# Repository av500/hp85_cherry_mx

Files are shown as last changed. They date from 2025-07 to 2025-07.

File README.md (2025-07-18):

 # HP 85 keyboard PCB using Cherry MX key switches

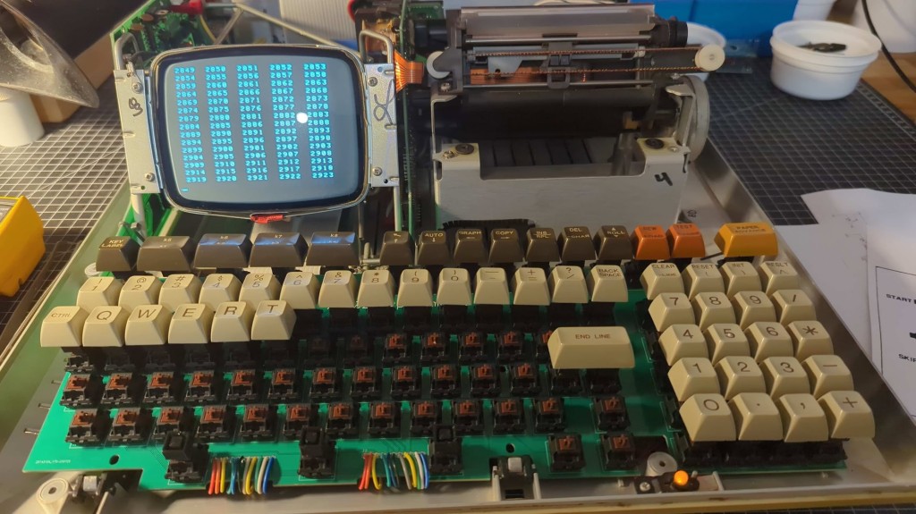
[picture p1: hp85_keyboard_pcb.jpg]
PCB image


(more images here: https://photos.app.goo.gl/D5baQ3GsZ5nenAsS6)

using the orignal keycaps with 3d-printerd adapters to connect the Hitek caps to the Cherry MX stem pattern:

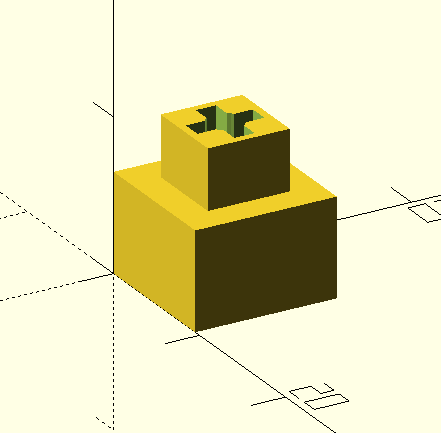
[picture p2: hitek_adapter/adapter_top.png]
adapter top view
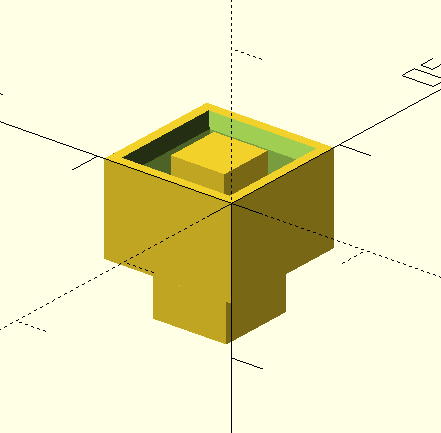
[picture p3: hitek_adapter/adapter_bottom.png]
adapter bottm view


the space bar uses three key switches in parallel with two 3d-printed standoffs in the corners:

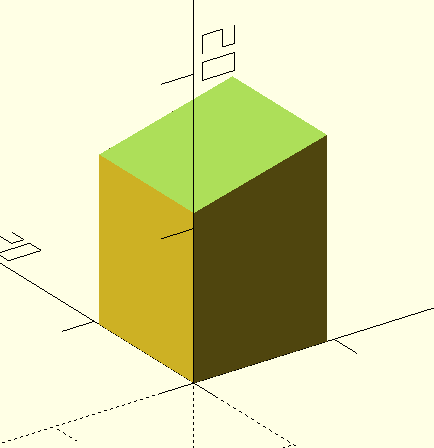
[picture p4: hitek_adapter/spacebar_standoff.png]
standoff 3d view
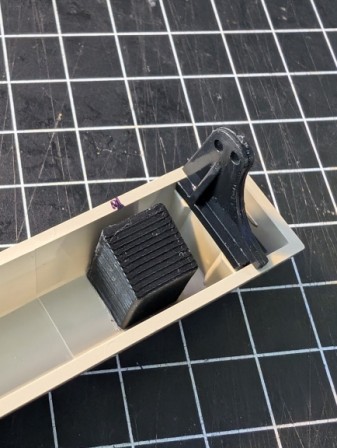
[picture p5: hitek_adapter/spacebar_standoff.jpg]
standoff view


**all 3d-printed part were designed to work with my (then) "not so good" printer, they might need some tweaking in terms of tolerances, I included the OpenSCAD source files.**

the PCB was made in standard 1.6mm thickness, so in order to make the keyboard stiffer a second PCB was placed below and the pin holes drilled out accordingly:

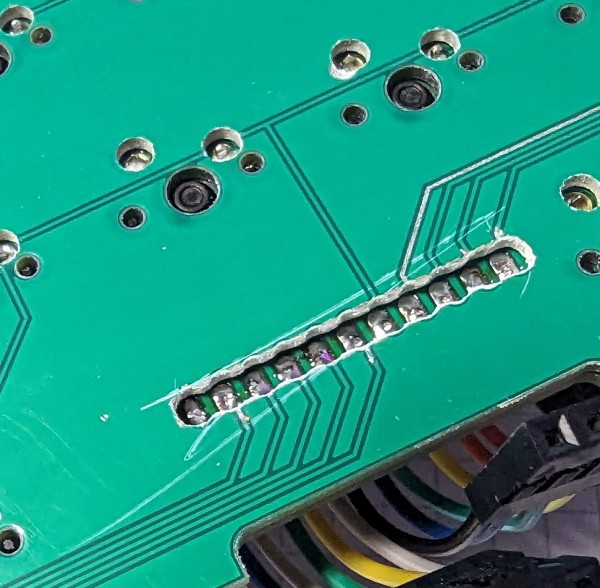
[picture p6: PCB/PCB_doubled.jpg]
doubled PCB


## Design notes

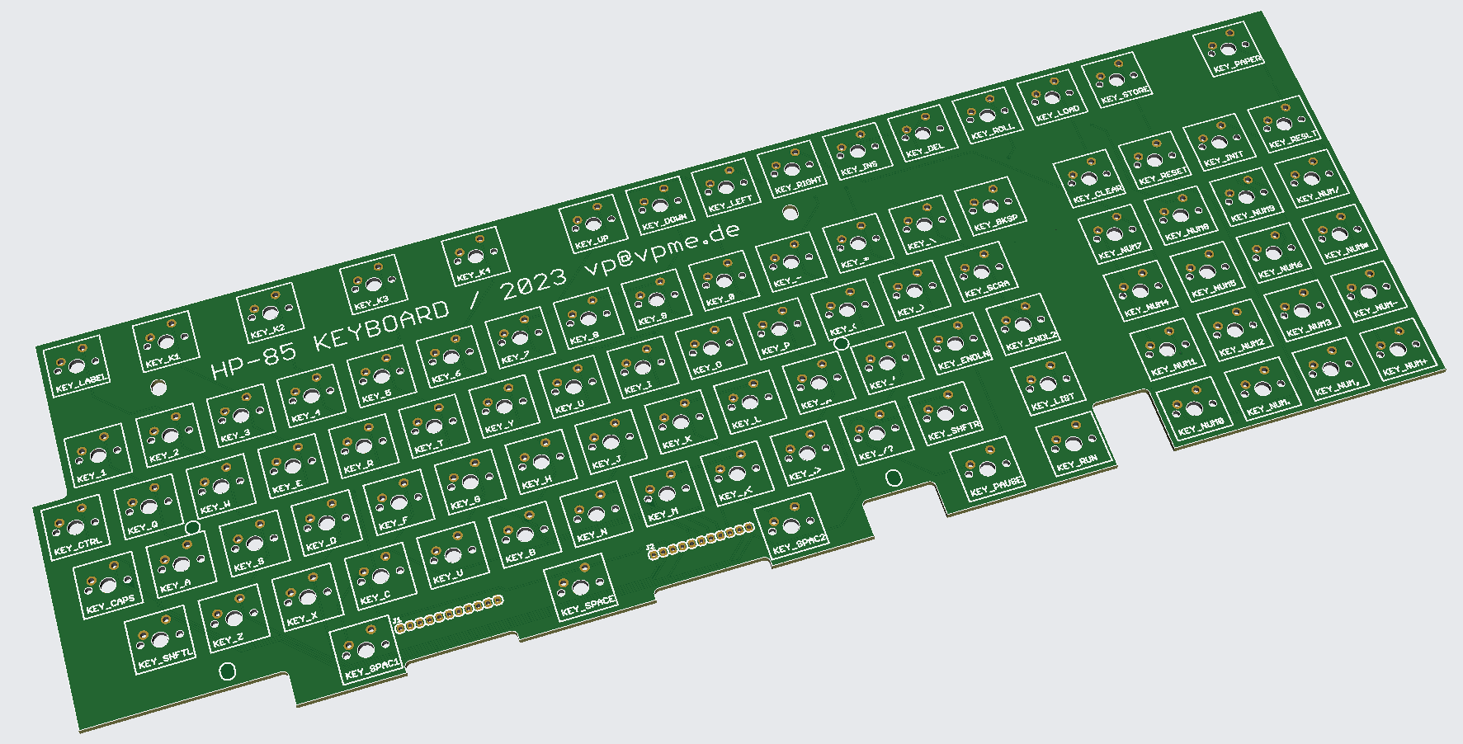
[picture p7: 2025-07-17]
PCB/HP85_keyboard_PCB_3d.png

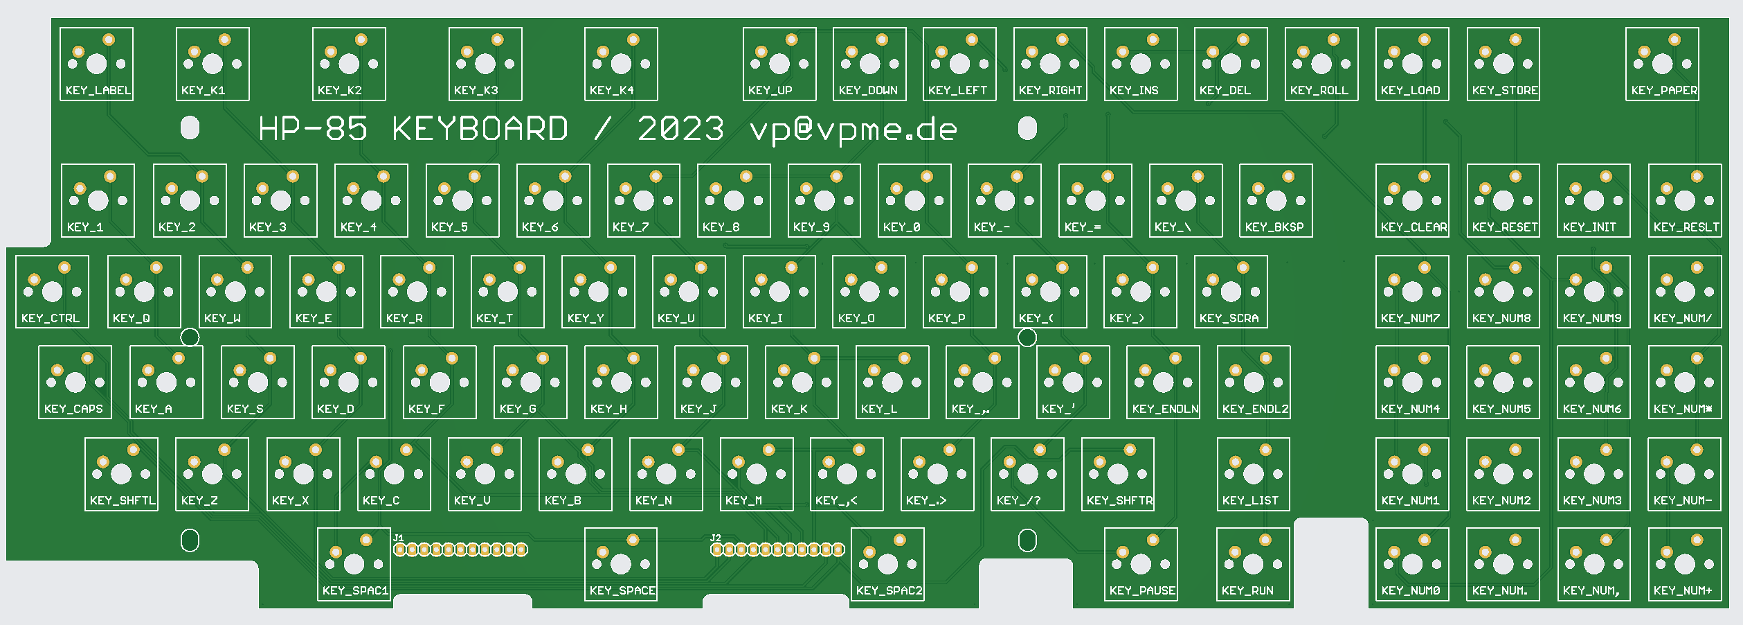
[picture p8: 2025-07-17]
PCB/HP85_keyboard_PCB_front.png

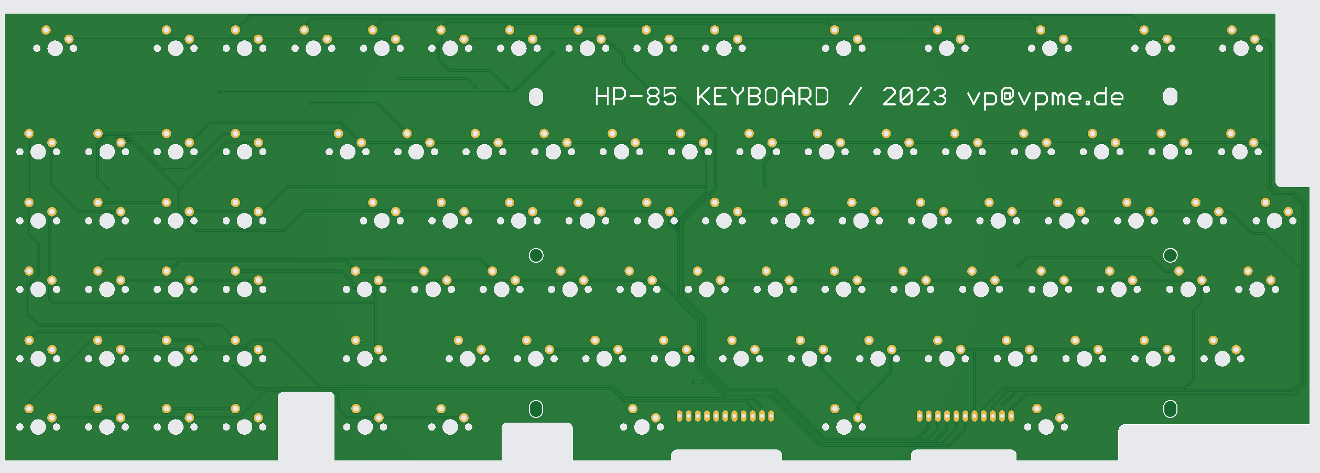
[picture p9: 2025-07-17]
PCB/HP85_keyboard_PCB_back.png

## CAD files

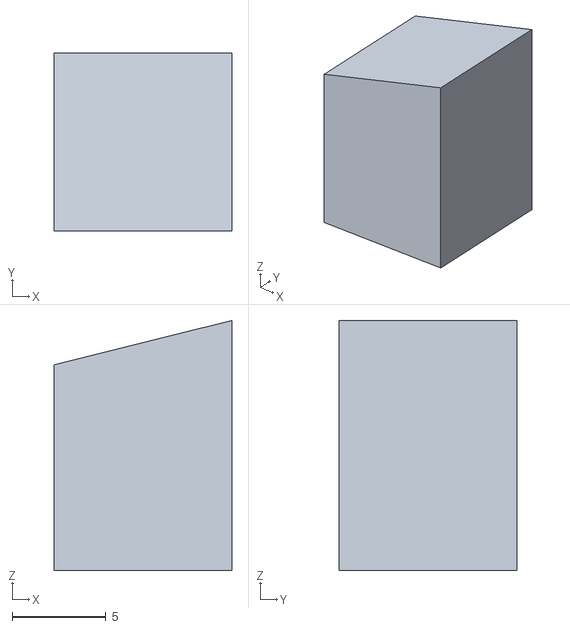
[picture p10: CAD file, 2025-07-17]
hitek_adapter/hitek_cherry_spacebar.stl
9.50 x 9.50 x 13.4

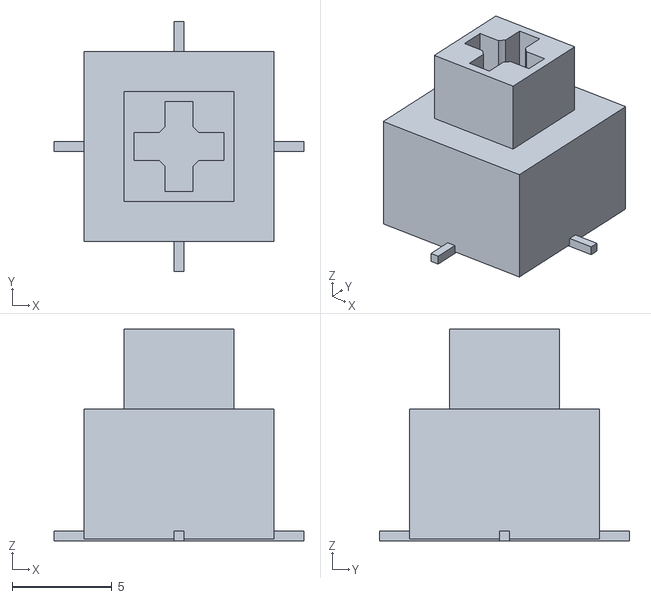
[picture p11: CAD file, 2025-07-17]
hitek_adapter/hitek_cherry_joined.stl
12.5 x 12.5 x 10.6

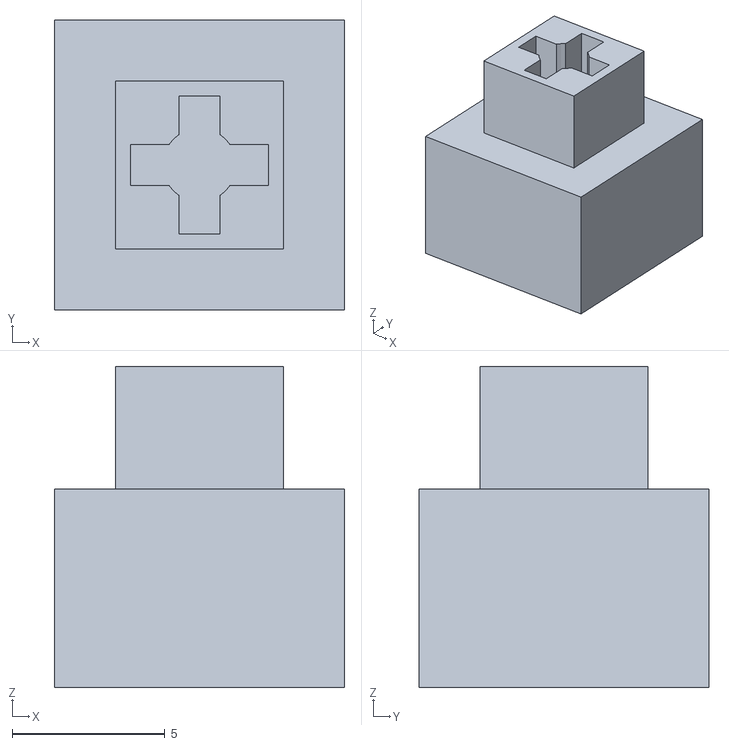
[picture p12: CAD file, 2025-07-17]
hitek_adapter/hitek_cherry.stl
9.50 x 9.50 x 10.5

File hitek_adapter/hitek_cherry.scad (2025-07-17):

lo1 = 9.5;
ho1 = 6.5;

li1 = 7.3;
hi1 = 5;

li2 = 4.0;
hi2 = ho1;

ofs1 = (lo1 - li1) / 2;
ofs2 = (lo1 - li2) / 2;

rr = 5.7;
o4 = (lo1) / 2;

module hitek() {

union() {
difference() {
	union() {
        translate([0, 0, 0])
			cube([lo1, lo1, ho1], center = false);
        }
    translate([ofs1, ofs1, 0]) cube([li1, li1, hi1], center = false);
translate([o4, o4, 0])rotate([0,0,45])cylinder(10,rr,0,$fn=4, center = false);
}
    translate([ofs2, ofs2, 0]) cube([li2, li2, hi2], center = false);
   // translate([0, 0, hi1]) cube([lo1, lo1, ho1-hi1], center = false);
}

}

cl = 5.5;
ch = 4;
cx = 4.5;
cw = 1.35;
ri = 1.2;

co1 = (cl - cx) / 2;
co2 = (cl - cw) / 2;

module cherry() {

union() {
difference() {
	union() {
        translate([0, 0, 0])
			cube([cl, cl, ch], center = false);
        }
    translate([co1, co2, 0]) cube([cx, cw, ch], center = false);
    translate([co2, co1, 0]) cube([cw, cx, ch], center = false);
    translate([cl/2, cl/2, 0])rotate([0,0,0])cylinder(10,ri,ri,$fn=40, center = false);
}
}

}

o3 = (lo1 - cl) / 2;
translate([0, 0, 0])hitek();
translate([o3, o3, ho1])cherry();

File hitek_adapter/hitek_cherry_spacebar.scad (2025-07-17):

$fn = 30;

dd = 9.5;
hh = 11;

angle = 14;

d2 = dd / cos(angle);
h2 = hh + d2 * sin(angle);

ofs = 0;


module space() {

difference() {
	union() {
        translate([0, 0, 0]) cube([dd,dd,h2], center = false);
    }
    translate([0, 0, hh]) 
        rotate([0,-angle,0])cube([d2, dd, 5], center = false);
}

}

translate([0, 0, 0])space();

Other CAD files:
hitek_adapter/hitek_cherry_joined.scad

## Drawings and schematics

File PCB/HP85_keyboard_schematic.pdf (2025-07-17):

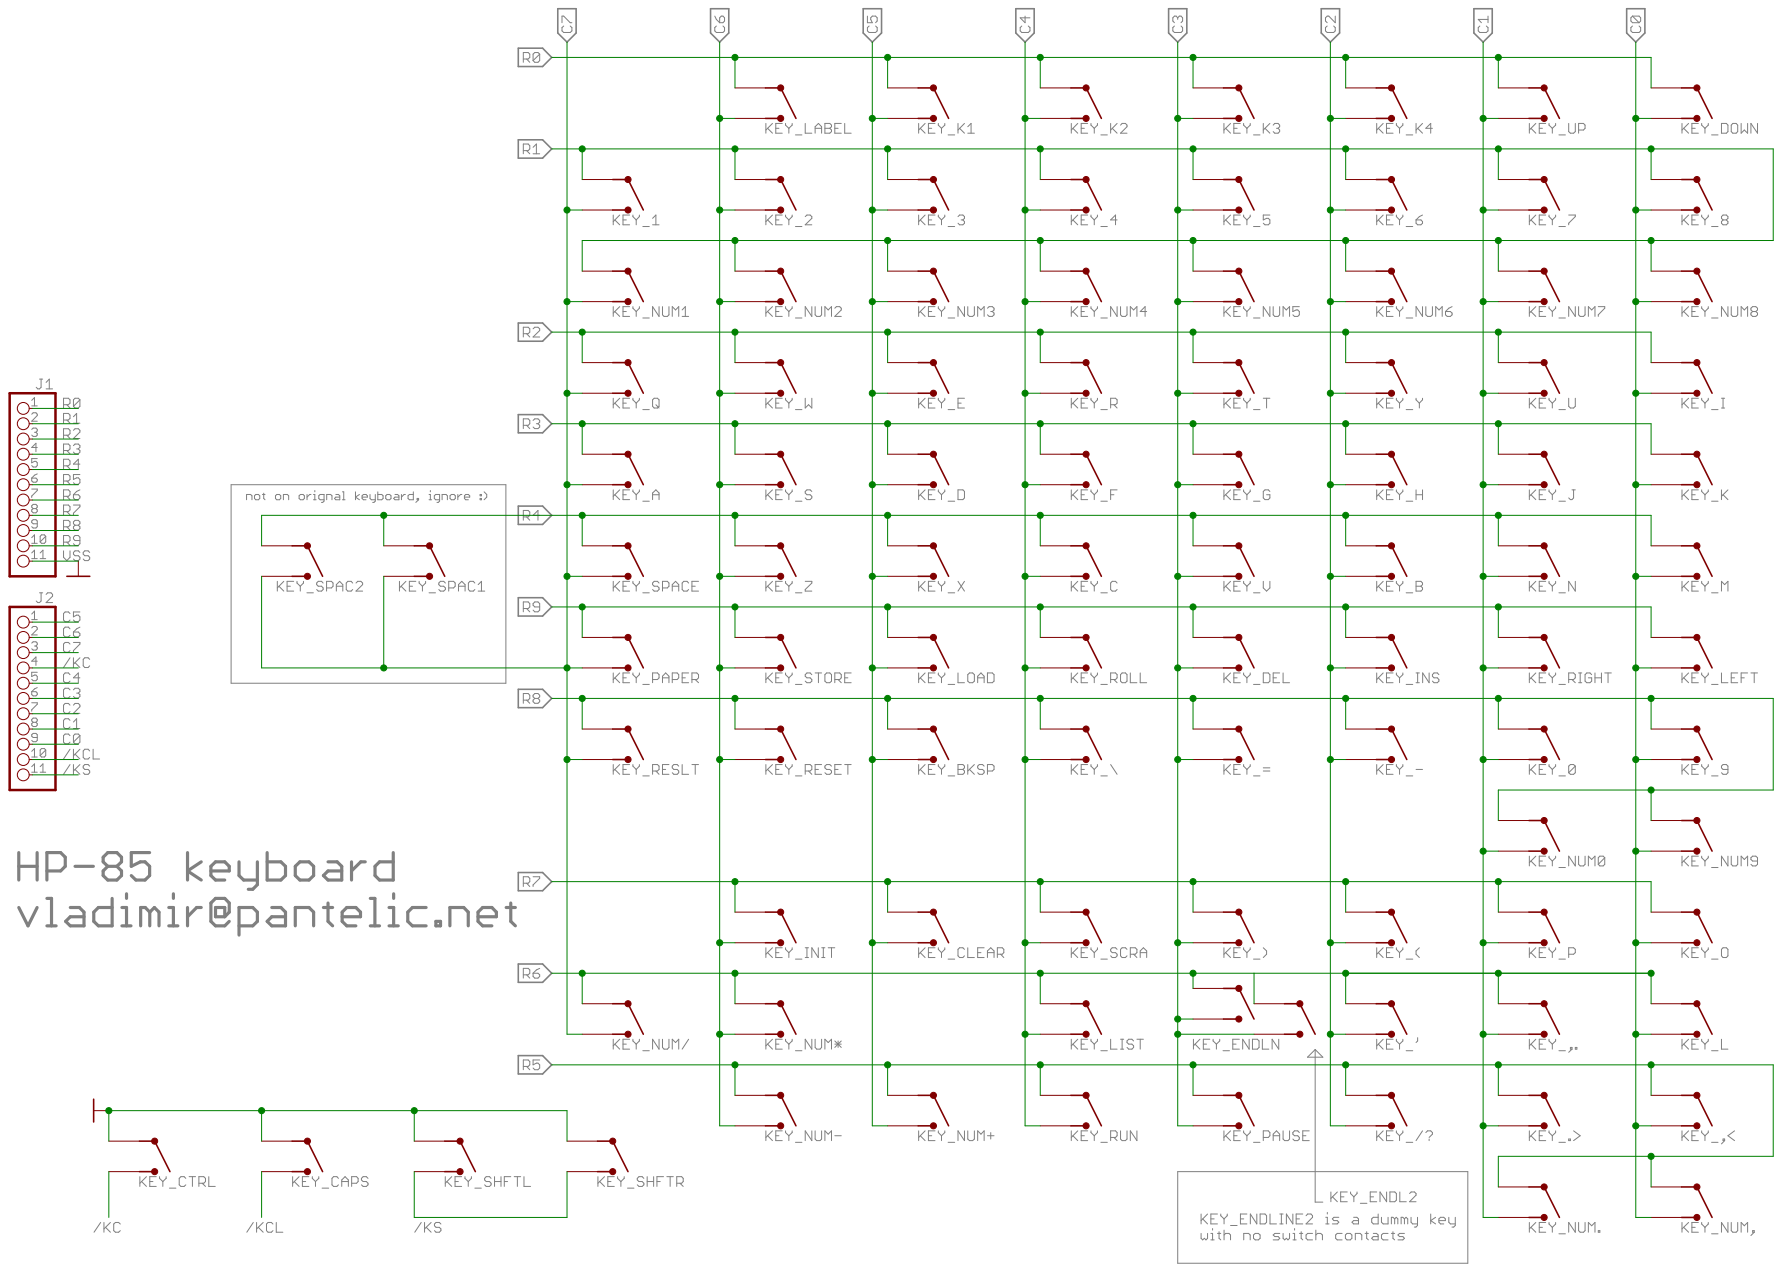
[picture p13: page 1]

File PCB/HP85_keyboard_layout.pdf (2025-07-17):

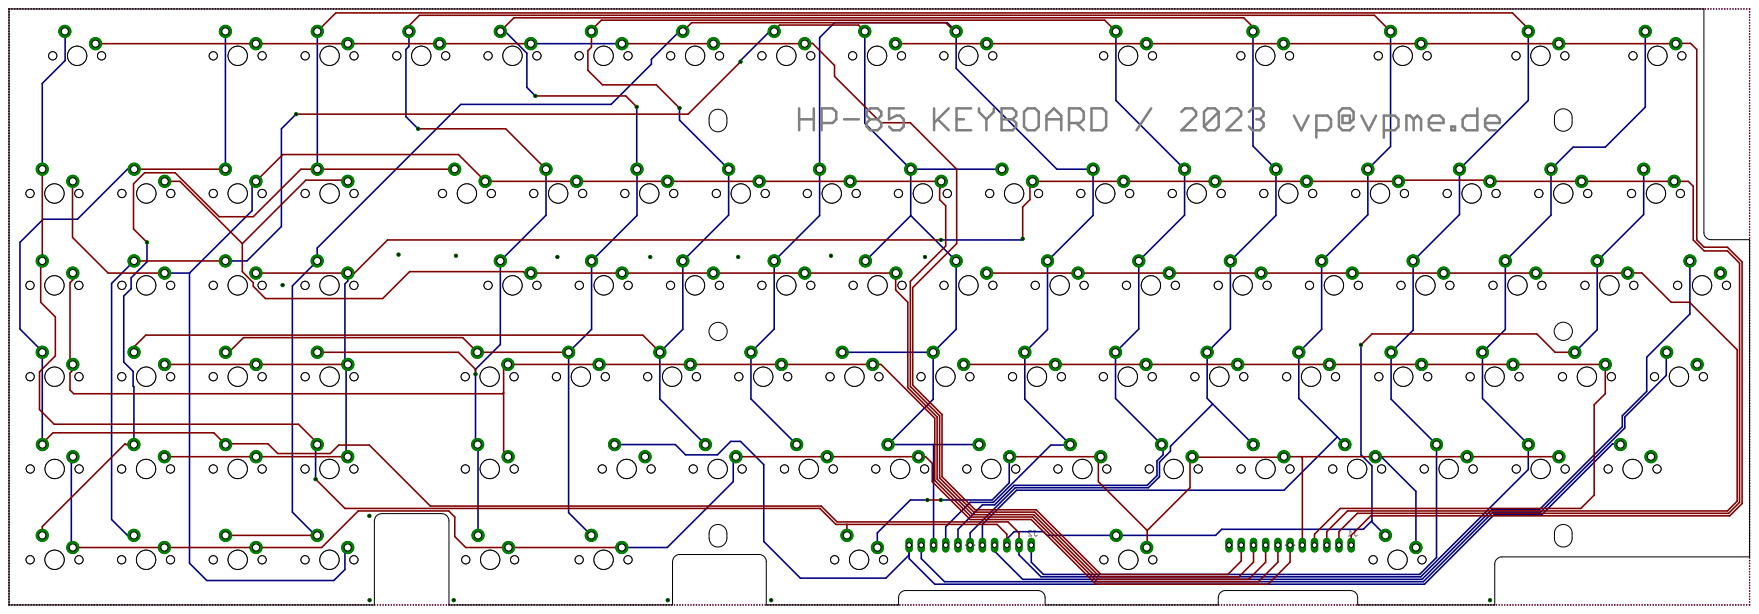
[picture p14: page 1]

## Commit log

2025-07-17 add some files
    [hitek_cherry.scad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]
2025-07-17 add doubled PCB image
